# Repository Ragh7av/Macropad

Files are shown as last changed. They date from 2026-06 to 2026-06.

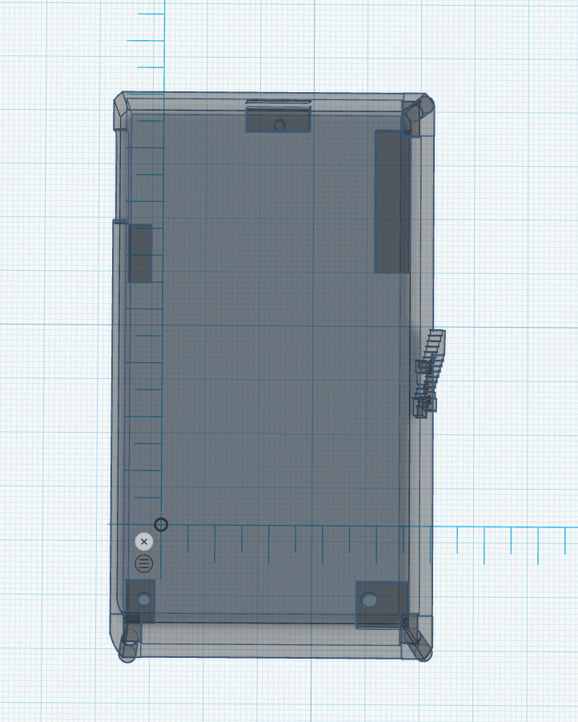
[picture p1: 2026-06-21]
IMAGES/Screenshot 2026-06-20 022025.png

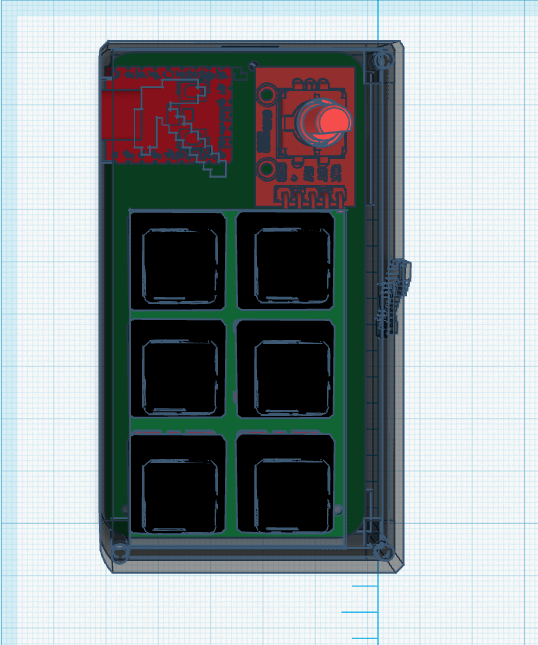
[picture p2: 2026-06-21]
IMAGES/Screenshot 2026-06-20 014024.png

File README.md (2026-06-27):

<h1 align="center">Macropad</h1> 
<div align="center">         
<p align="center">
        

A custom 6-key custom macropad with a rotary encoder, Cherry MX red mechanical switches, a custom PCB, and a 3D-printed case to take your workflow to the next level.
</p>
https://cad.onshape.com/documents/96bc1078680b64831b101746/w/834816f7826d3f1ee40a2d83/e/93c4e7053cae44b7b10a563c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
<h1 align="center">Overview</h1>
        
<p align="center">This project is a custom desktop macropad built around the RP2040-Zero. It includes 6 Cherry MX Red mechanical switches for satisfying tactile sounds while clocking, a KY-040 rotary encoder for volume or scroll control, a custom-designed PCB, and a sleek 3D-printed two-part enclosure. 

# Repository Contents

| Path | What it contains |
| --- | --- |
| [`3D_PRINTS`](https://github.com/Ragh7av/Macropad/tree/main/3D_PRINTS) | STL files for quick access to 3D printing the top and bottom enclosure halves |
| [`ASSEMBLY`](https://github.com/Ragh7av/Macropad/tree/main/ASSEMBLY) | Files related to the mechanical assembly of the macropad |
| [`BOM`](https://github.com/Ragh7av/Macropad/tree/main/BOM) | Bill of materials details and cost breakdowns |
| [`FIRMWARE`](https://github.com/Ragh7av/Macropad/tree/main/FIRMWARE) | Firmware code (C++/CircuitPython/KMK) to program the keys and encoder |
| [`GERBERS`](https://github.com/Ragh7av/Macropad/tree/main/GERBERS) | Ready-to-manufacture Gerber files for fabricating the PCB |
| [`IMAGES`](https://github.com/Ragh7av/Macropad/tree/main/IMAGES) | Photos and screenshots of the project |
| [`PCB`](https://github.com/Ragh7av/Macropad/tree/main/PCB) | KiCad schematic and PCB layout files |
| [`ZINE`](https://github.com/Ragh7av/Macropad/tree/main/ZINE) | Project zine documentation |
| [`CAD`](CAD) | Project 3D models |

<h1 align="center">Why am I even building this?</h1>
<p align="center">
 I built this project as a part of an event called <a href="https://fallout.hackclub.com">Fallout</a>, organized by a non-profit organization called <a href="https://hackclub.com">Hack Club</a>. We build and ship hardware projects, and for that, we get some cool gifts and grants to build it IRL. After building hardware projects for 60 hours, we get invited to Shenzhen, China for a Hardware Hackathon. I am building this project to work toward those 60 hours.
 </p>

<h1 align="center">Why Macropad?</h1>

So I spend a lot of time at my desk doing coding, editing, and general productivity tasks. I frequently need quick access to specific shortcuts, media controls, and repetitive keystrokes that are tedious to execute on a standard keyboard. I created this project  to solve these problems and help myself get supercalifragilisticexpialidocious in building super cool hardware things while optimizing my workflow. 

# Zine 
Zine

# Printed Circuit Board (PCB)




#  Schematic


# CAD











<h1 align="center">The Features</h1>
</div>

1. **6 Programmable Keys**: Features 6 Cherry MX Red linear mechanical switches for smooth, fast, and customizable keystrokes (copy/paste, media navigation, macro strings, etc.).
2. **Rotary Encoder**: Includes a built-in KY-040 rotary encoder with a push-button function, perfect for controlling system volume, zooming, or scrolling through timelines.
3. **Custom PCB**: A printed circuit board routing the switches and encoder directly to the RP2040-Zero while looking beautiful with a custom silkscreen designs.
4. **RP2040-Zero Brains**: Powered by the compact Raspberry Pi RP2040-Zero microcontroller, ensuring fast response times and easy programmability.
5. **3D Printed Enclosure**: A custom-designed two-part (top and bottom) FDM 3D-printed case to keep the electronics safe and look great on a desk.

# The Components Used

1. RP2040-Zero (Raspberry Pi Microcontroller)
2. KY-040 Rotary Encoder Module
3. Cherry MX RED mechanical switches (x6)
4. PBT DSA Blank Keycaps for MX Switches (x6)
5. Custom Printed Circuit Board (PCB)
6. 3D Printed Case (Top and Bottom halves)

# Bill of Materials

| Component Name | Quantity | Price (₹) | Total Cost (₹) | Shipping (₹) | Total Price (₹) |
| --- | --- | --- | --- | --- | --- |
| PCB (Robu PCB Manufacturing) | 1 | ₹180 | ₹900 | ₹49 | ₹949 |
| Keycaps for MX keys (ATORSE 12Pcs Blank) | 6 | ₹52.25 | ₹627 | Free | ₹627 |
| Cherry MX RED mechanical keys | 6 | ₹44.9 | ₹449 | Free | ₹449 |
| Raspberry Pi RP2040 Zero | 1 | ₹235 | ₹235 | ₹24.5 | ₹259.5 |
| KY-040 Rotary encoder | 1 | ₹59 | ₹59 | ₹24.5 | ₹83.5 |
| Case bottom half (at 40% infill) | 1 | ₹159 | ₹159 | ₹49.5 | ₹208.5 |
| Case top half (at 40% infill) | 1 | ₹90 | ₹90 | ₹49.5 | ₹139.5 |
| **Subtotal** | | | **₹2519** | **₹197** | **₹2716** |

# How to Build it?

**To replicate, follow the steps below:**
1) First, grab the PCB Gerber files from the `GERBERS` folder and send them to your preferred PCB manufacturer (like Robu, JLCPCB, etc.).
2) Next, grab the 3D models from the `3D_PRINTS` folder and print the top and bottom case halves (recommended 40% infill for a solid feel).
3) Purchase the parts mentioned in the **BOM**.
4) Solder the RP2040-Zero, Cherry MX switches, and the rotary encoder onto your fabricated PCB.
5) Flash the firmware from the `FIRMWARE` folder onto your RP2040-Zero via USB-C.
6) Test the keys and encoder on your computer to ensure all keystrokes register. 
7) Assemble the PCB into the 3D-printed shell, pop on your keycaps, and secure everything together!

## Firmware setup
 - Connect your RP2040-Zero to your computer via USB-C.
 - If using Arduino IDE: Select the appropriate RP2040 board under Tools > Board, select the Port, compile, and click Upload.
 - Customize your keybindings in the firmware code to map to your preferred macros, shortcuts, or media controls before uploading.

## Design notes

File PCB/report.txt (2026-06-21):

Plotted to 'C:\Users\Pc\OneDrive\Documents\Speedey\Macropad\Gerbers\Macropad-F_Cu.gtl'.
Plotted to 'C:\Users\Pc\OneDrive\Documents\Speedey\Macropad\Gerbers\Macropad-B_Cu.gbl'.
Plotted to 'C:\Users\Pc\OneDrive\Documents\Speedey\Macropad\Gerbers\Macropad-F_Paste.gtp'.
Plotted to 'C:\Users\Pc\OneDrive\Documents\Speedey\Macropad\Gerbers\Macropad-B_Paste.gbp'.
Plotted to 'C:\Users\Pc\OneDrive\Documents\Speedey\Macropad\Gerbers\Macropad-F_Silkscreen.gto'.
Plotted to 'C:\Users\Pc\OneDrive\Documents\Speedey\Macropad\Gerbers\Macropad-B_Silkscreen.gbo'.
Plotted to 'C:\Users\Pc\OneDrive\Documents\Speedey\Macropad\Gerbers\Macropad-F_Mask.gts'.
Plotted to 'C:\Users\Pc\OneDrive\Documents\Speedey\Macropad\Gerbers\Macropad-B_Mask.gbs'.
Plotted to 'C:\Users\Pc\OneDrive\Documents\Speedey\Macropad\Gerbers\Macropad-Edge_Cuts.gm1'.
Info: Done.

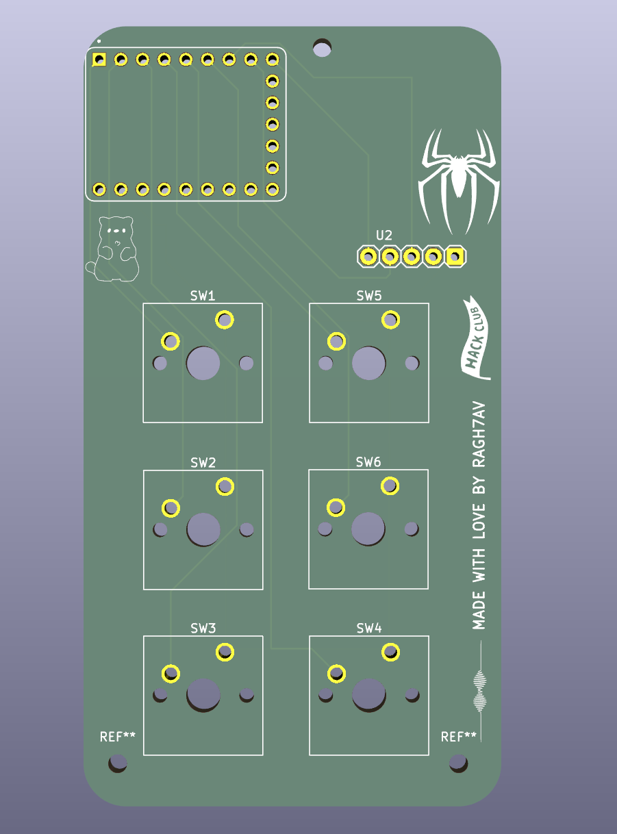
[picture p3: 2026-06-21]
IMAGES/Screenshot 2026-06-19 184742.png

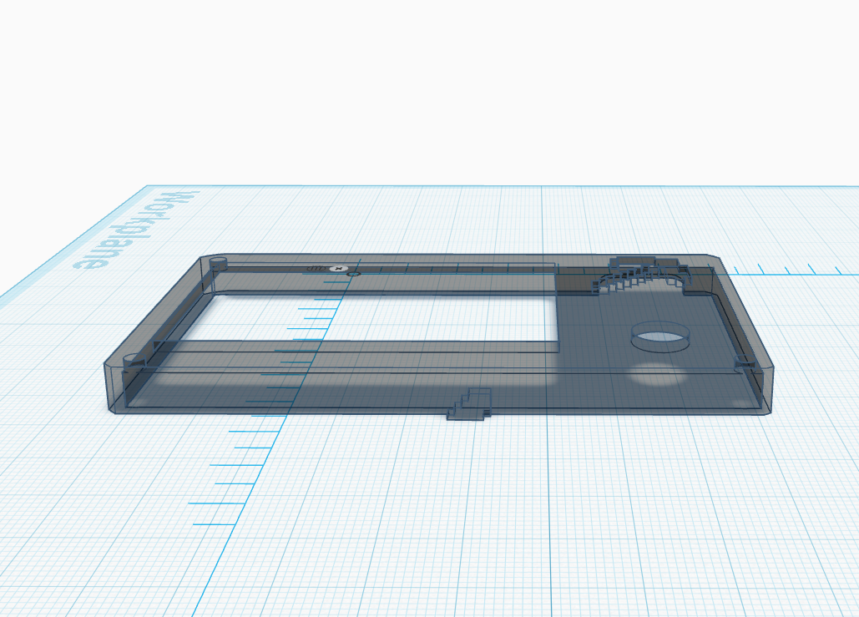
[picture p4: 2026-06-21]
IMAGES/Screenshot 2026-06-20 021840.png

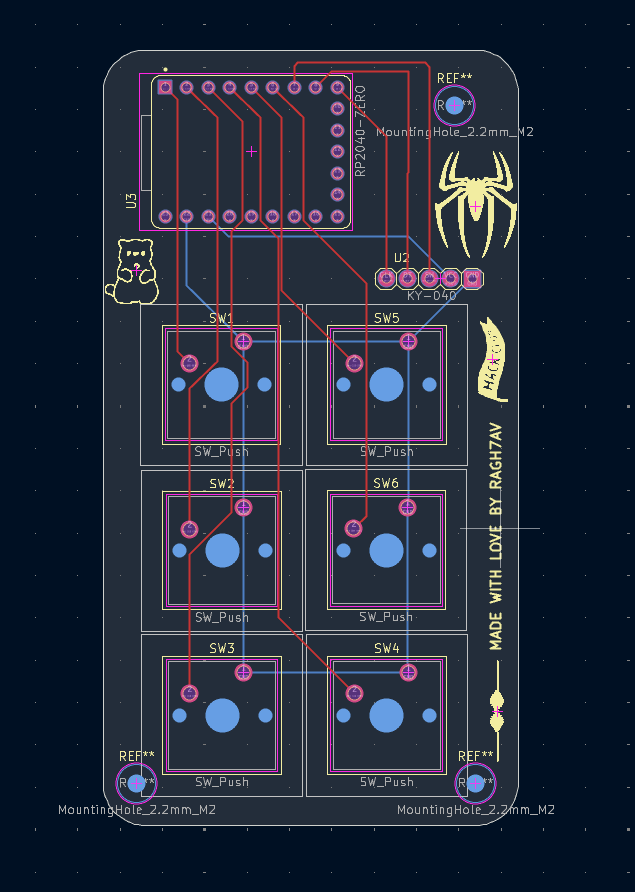
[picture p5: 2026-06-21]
IMAGES/Screenshot 2026-06-19 180719.png

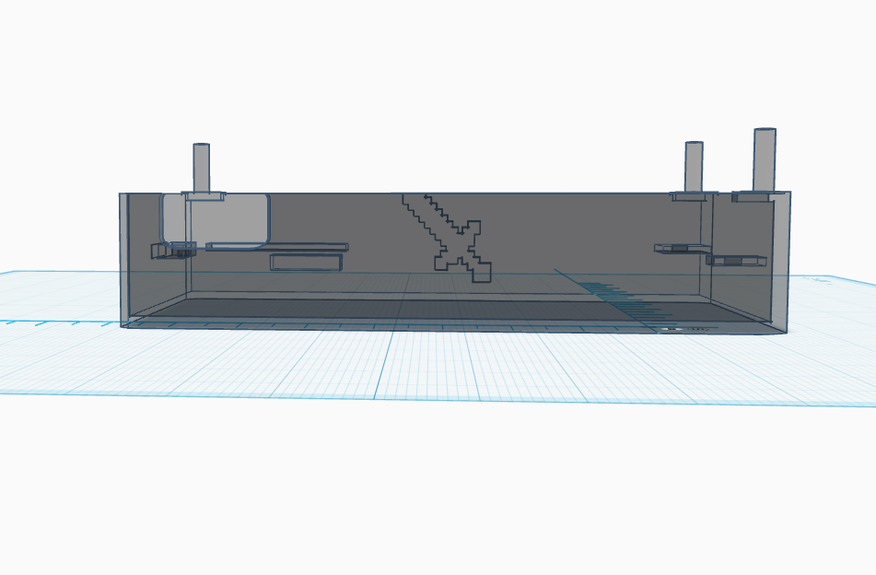
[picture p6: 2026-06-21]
IMAGES/Screenshot 2026-06-20 022005.png

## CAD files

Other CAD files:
CAD/Assembly macropad.stl
CAD/Macropad_assembly_onshape.step
PCB/mp2.stl
PCB/.stl
CAD/bottom case macropad.stl
CAD/top case macropad.stl

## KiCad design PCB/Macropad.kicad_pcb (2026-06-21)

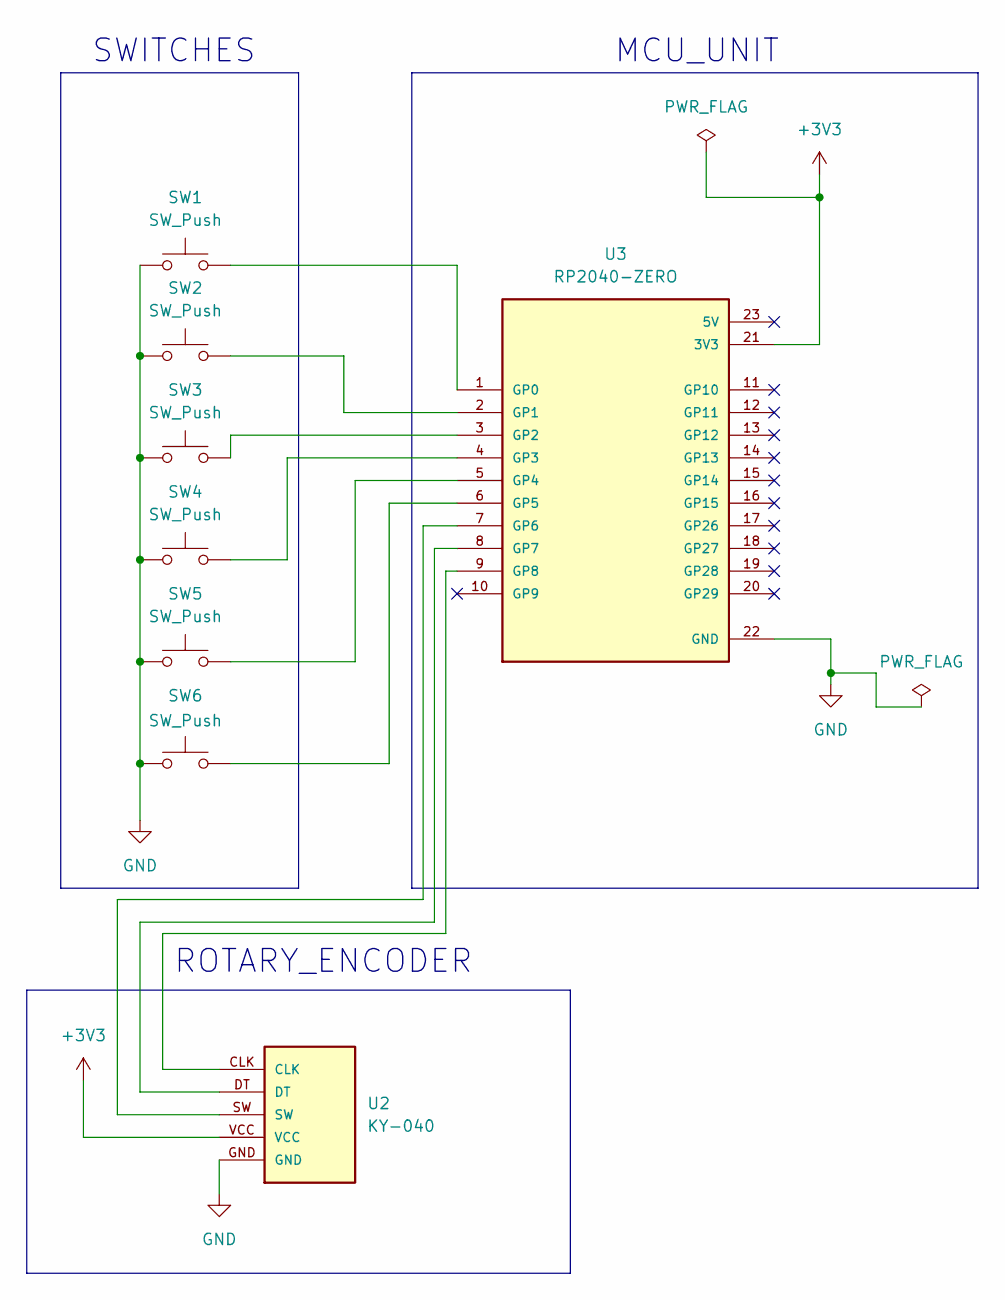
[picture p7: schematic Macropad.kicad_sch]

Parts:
SW1, SW2, SW3, SW4, SW5, SW6: SW_Push; SW_Cherry_MX_1.00u_PCB
U2: KY-040; KY-040-PORT
U3: RP2040-ZERO; FP_RP2040; PARTREV NA

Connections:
+3V3: U2.VCC, U3.21 (3V3)
GND: SW1.1, SW2.1, SW3.1, SW4.1, SW5.1, SW6.1, U2.GND, U3.22 (GND)
unnamed: SW1.2, U3.1 (GP0)
unnamed: SW2.2, U3.2 (GP1)
unnamed: SW3.2, U3.3 (GP2)
unnamed: SW4.2, U3.4 (GP3)
unnamed: SW5.2, U3.5 (GP4)
unnamed: SW6.2, U3.6 (GP5)
unnamed: U2.SW, U3.7 (GP6)
unnamed: U2.DT, U3.8 (GP7)
unnamed: U2.CLK, U3.9 (GP8)

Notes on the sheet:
ROTARY_ENCODER
SWITCHES
MCU_UNIT

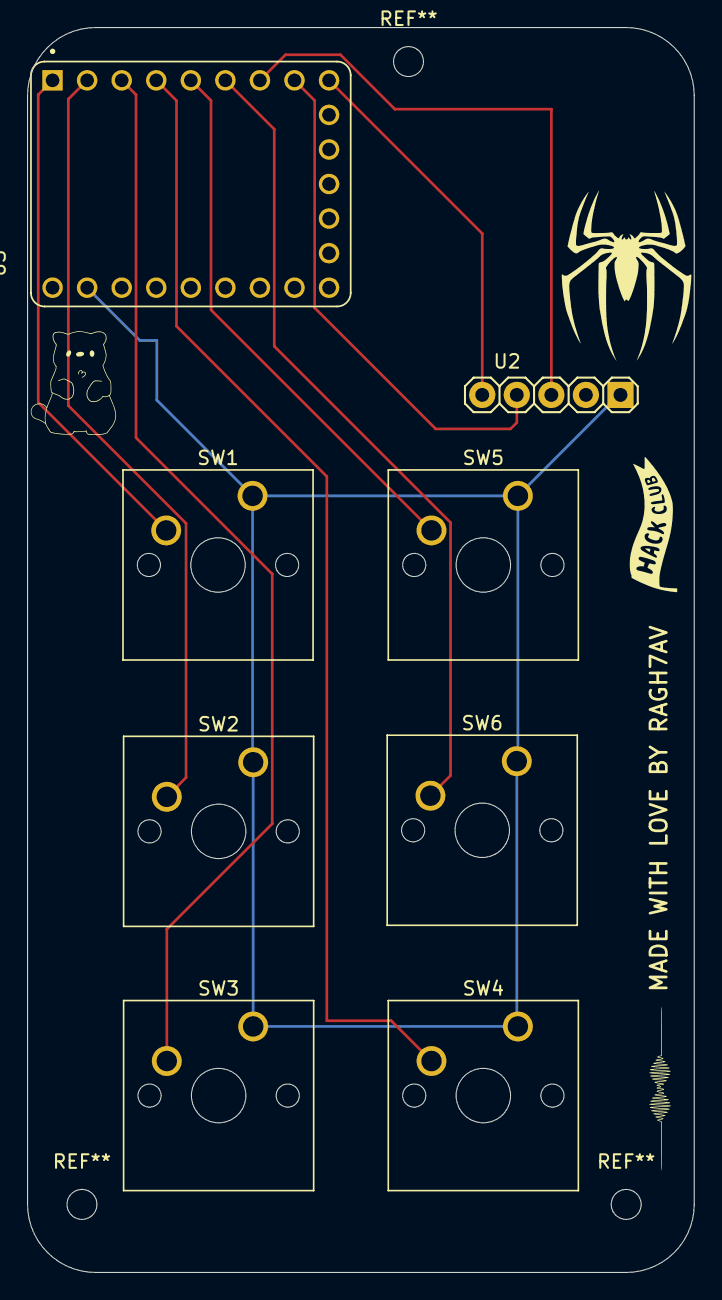
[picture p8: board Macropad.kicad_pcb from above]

Board: 2 copper layers, 49.0 x 91.5 mm, 8 parts (0 on the bottom side), 11 nets.

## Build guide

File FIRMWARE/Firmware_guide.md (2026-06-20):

### Option A: KMK Firmware 
KMK is interpreted dynamically, allowing you to edit your keymaps on the fly by simply saving a text file.
1. Install [CircuitPython for the RP2040-Zero](https://circuitpython.org/board/waveshare_rp2040_zero/).
2. Copy the `kmk` folder from the [official KMK firmware repo](https://github.com/KMKfw/kmk_firmware) to the root of your mounted `CIRCUITPY` drive.
3. Drop the `kb.py` and `main.py` files from the `/KMK` folder in this repository directly onto the drive.

### Option B: QMK Firmware 
QMK provides lower-level hardware control, utilizing data-driven JSON configurations.
1. Copy the `qmk` folder into your local `qmk_firmware/keyboards/` directory.
2. Compile the firmware from your terminal:
   ```bash
   qmk compile -kb macropad -km default

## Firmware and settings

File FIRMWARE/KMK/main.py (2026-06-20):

import board
import time
import math
import digitalio
from kmk.kmk_keyboard import KMKKeyboard
from kmk.keys import KC
from kmk.modules.layers import Layers
from kmk.modules.rotary_encoder import RotaryEncoderHandler

keyboard = KMKKeyboard()

# Core Modules
keyboard.modules.append(Layers())
encoder_handler = RotaryEncoderHandler()
keyboard.modules.append(encoder_handler)

# Base Keymap (Linear list matching GP0 to GP8)
keyboard.keymap = [
    [
        KC.MRWD, KC.MPLY, KC.MFFD,         # Row 1: GP0, GP1, GP2
        KC.MSEL, KC.CALC, KC.LGUI(KC.R),   # Row 2: GP3, GP4, GP5
        KC.LEFT, KC.RIGHT, KC.LGUI(KC.L),  # Row 3: GP6, GP7, GP8
    ]
]

# Encoder Configuration
encoder_handler.pins = (board.GP26, board.GP27)
encoder_handler.divisor = 4
encoder_handler.map = [KC.VOLD, KC.VOLU]

# Encoder Switch Configuration
encoder_button = digitalio.DigitalInOut(board.GP28)
encoder_button.switch_to_input(pull=digitalio.Pull.UP)

# Lighting Engine Engine State
led_modes = ["Solid Pulse", "Rainbow Spectrum", "Wave Motion", "Sunlight Ripple"]
current_mode = 0
last_button_state = True
last_led_tick = 0
led_frame_rate = 0.03  # Locks animations to ~33 FPS to prioritize keystroke latency

def calculate_lighting_effects():
    timestamp = time.monotonic()
    
    if led_modes[current_mode] == "Solid Pulse":
        speed = timestamp * 1.5
        for i, (x, y) in enumerate(keyboard.led_positions):
            pulse = int((math.sin(speed + x * 0.5 + y * 0.5) + 1) * 127)
            keyboard.leds[i] = (0, 0, pulse, pulse // 2)
            
    elif led_modes[current_mode] == "Rainbow Spectrum":
        shift = int(timestamp * 45) % 255
        for i in range(keyboard.num_leds):
            hue = (i * 18 + shift) % 255
            if hue < 85:
                keyboard.leds[i] = (hue * 3, 255 - hue * 3, 0, 0)
            elif hue < 170:
                hue -= 85
                keyboard.leds[i] = (255 - hue * 3, 0, hue * 3, 0)
            else:
                hue -= 170
                keyboard.leds[i] = (0, hue * 3, 255 - hue * 3, 0)
                
    elif led_modes[current_mode] == "Wave Motion":
        wave_speed = timestamp * 2.0
        for i, (x, y) in enumerate(keyboard.led_positions):
            intensity = int((math.sin(wave_speed + (x * 0.8) + (y * 0.5)) + 1) * 127)
            keyboard.leds[i] = (0, intensity // 2, intensity, 0)
            
    elif led_modes[current_mode] == "Sunlight Ripple":
        shimmer = timestamp * 1.2
        for i, (x, y) in enumerate(keyboard.led_positions):
            glow = int((math.sin(shimmer + x + y) + 1) * 80)
            keyboard.leds[i] = (0, glow // 2, glow, 0)

    keyboard.leds.show()

def process_hardware_events():
    global current_mode, last_button_state
    button_now = encoder_button.value
    
    if not button_now and last_button_state:
        current_mode = (current_mode + 1) % len(led_modes)
        keyboard.leds.fill((0, 0, 0, 0))
        keyboard.leds.show()
        time.sleep(0.04) # Hardware debounce
        
    last_button_state = button_now

if __name__ == "__main__":
    while True:
        keyboard.go()
        process_hardware_events()
        
        # Non-blocking render loop
        current_tick = time.monotonic()
        if current_tick - last_led_tick > led_frame_rate:
            calculate_lighting_effects()
            last_led_tick = current_tick

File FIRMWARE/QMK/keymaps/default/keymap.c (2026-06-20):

#include QMK_KEYBOARD_H

const uint16_t PROGMEM keymaps[][MATRIX_ROWS][MATRIX_COLS] = {
    [0] = LAYOUT(
        KC_MRWD, KC_MPLY, KC_MFFD,    
        KC_MSEL, KC_CALC, LCMD(KC_R), 
        KC_LEFT, KC_RGHT, LCMD(KC_L)  
    )
};

// Rotary Encoder Polling
bool encoder_update_user(uint8_t index, bool clockwise) {
    if (index == 0) {
        if (clockwise) {
            tap_code(KC_VOLU);
        } else {
            tap_code(KC_VOLD);
        }
    }
    return false;
}

// Encoder Button Mapping to RGB Engine
void matrix_scan_user(void) {
    static pin_t sw_pin = GP28;
    static bool last_state = true;

    bool current_state = gpio_read_pin(sw_pin);
    if (!current_state && last_state) {
        rgblight_step(); 
        wait_ms(50); // Simple mechanical debounce logic 
    }
    last_state = current_state;
}

void keyboard_post_init_user(void) {
    setPinInputHigh(GP28); // Force internal pull-up on the encoder switch
}

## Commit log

2026-06-25 Add Macropad project files with LFS
    [.stl, Assembly macropad.stp, bottom case macropad.stl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]
2026-06-27 Update PNGs and project files
    [Assembly macropad.stl, Macropad_assembly_onshape.step, bottom case macropad.stl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]
